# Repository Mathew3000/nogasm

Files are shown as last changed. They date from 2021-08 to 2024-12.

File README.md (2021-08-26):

# Warning
The pcb is not fully tested yet. Might not work as expected.

# Mods
24 LEDs on pc edge <br/>
ESP32 instead of a teensy/teensyduino<br/>
Includes KiCad files<br/>

### Case
The case can be 3D printed without support material. Print at least the top half of the case in white to see the LED display beneath. 
Files will be uploaded once tested.

### PCB
All the Gerber files are included to order a set of PCBs. The PCB has mostly surface-mount components, and is doable with either a soldering iron or solder paste.
The components have been chosen so they can be assembled by the JLCpcb Assembly service. The only part that needs to be sourced from elsewhere and handsoldered is the pressure gauge.

### Vibrator
The vibrator is made from a Mabuchi RS-555PH motor, with an eccentric mass pressed onto the shaft. These can be purchased pre-assembled, or built from the motor and some .88" to 1" diameter cylindrical brass stock.
The vibrator case is compatible with attachments designed for the Hitachi Magic Wand. The motor is press-fit or glued into the two halves of the case.

This repository is a fork of the nogasm project by headcrabned https://github.com/nogasm/nogasm 
This work is licensed under a Creative Commons Attribution-NonCommercial 4.0 International Licence, available at http://creativecommons.org/licenses/by-nc/4.0/.

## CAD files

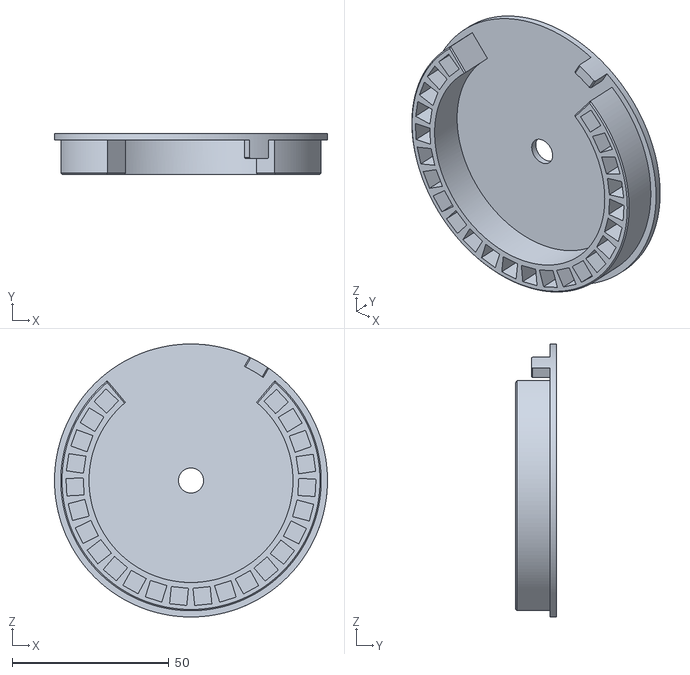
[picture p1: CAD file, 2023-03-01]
case/CaseUpper.stl
87.0 x 13.0 x 87.0

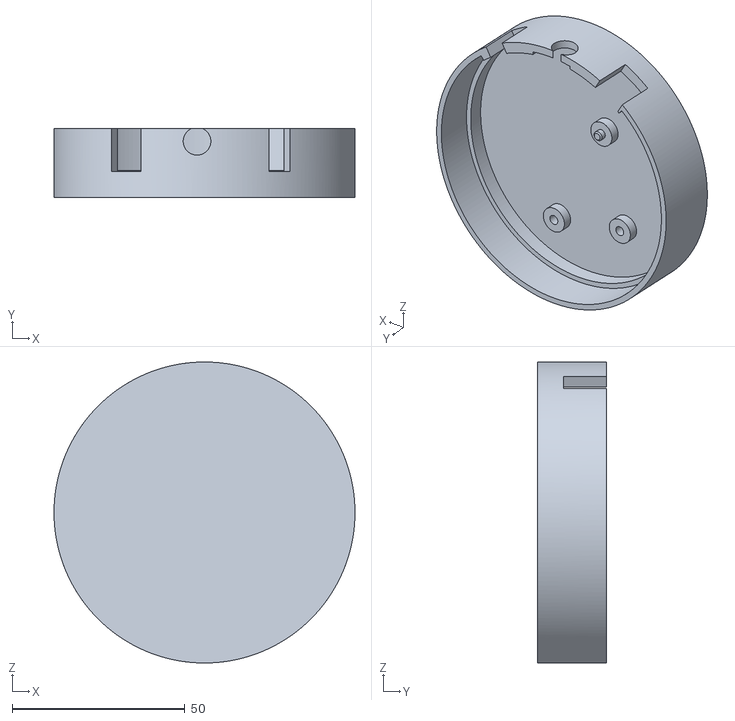
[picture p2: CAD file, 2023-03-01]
case/CaseLower.stl
87.0 x 20.0 x 87.0

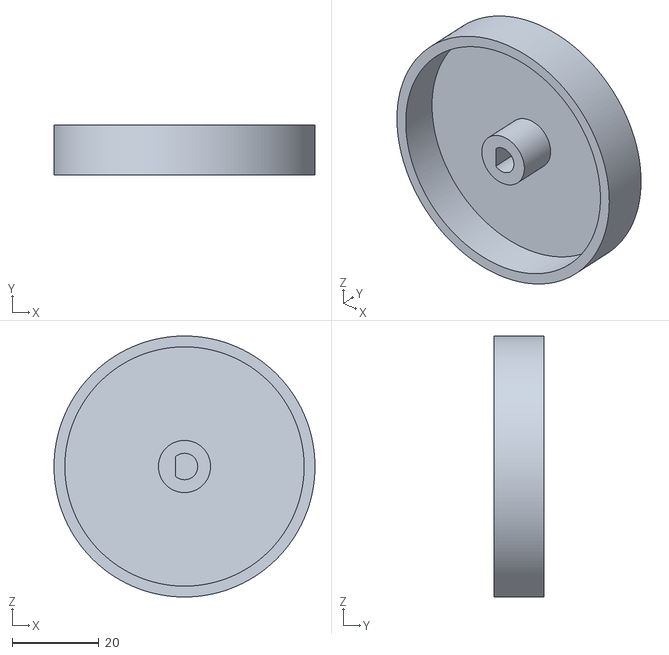
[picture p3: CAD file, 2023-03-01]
case/Knob.stl
60.0 x 11.5 x 60.0

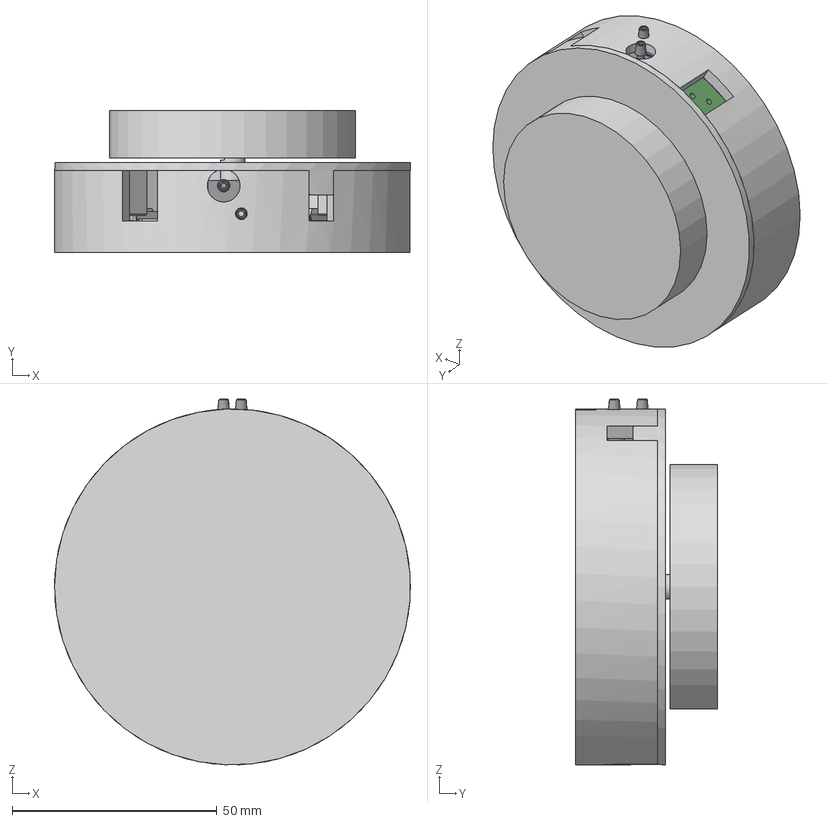
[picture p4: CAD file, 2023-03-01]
case/Case.step
87.0 x 34.6 x 89.4 mm

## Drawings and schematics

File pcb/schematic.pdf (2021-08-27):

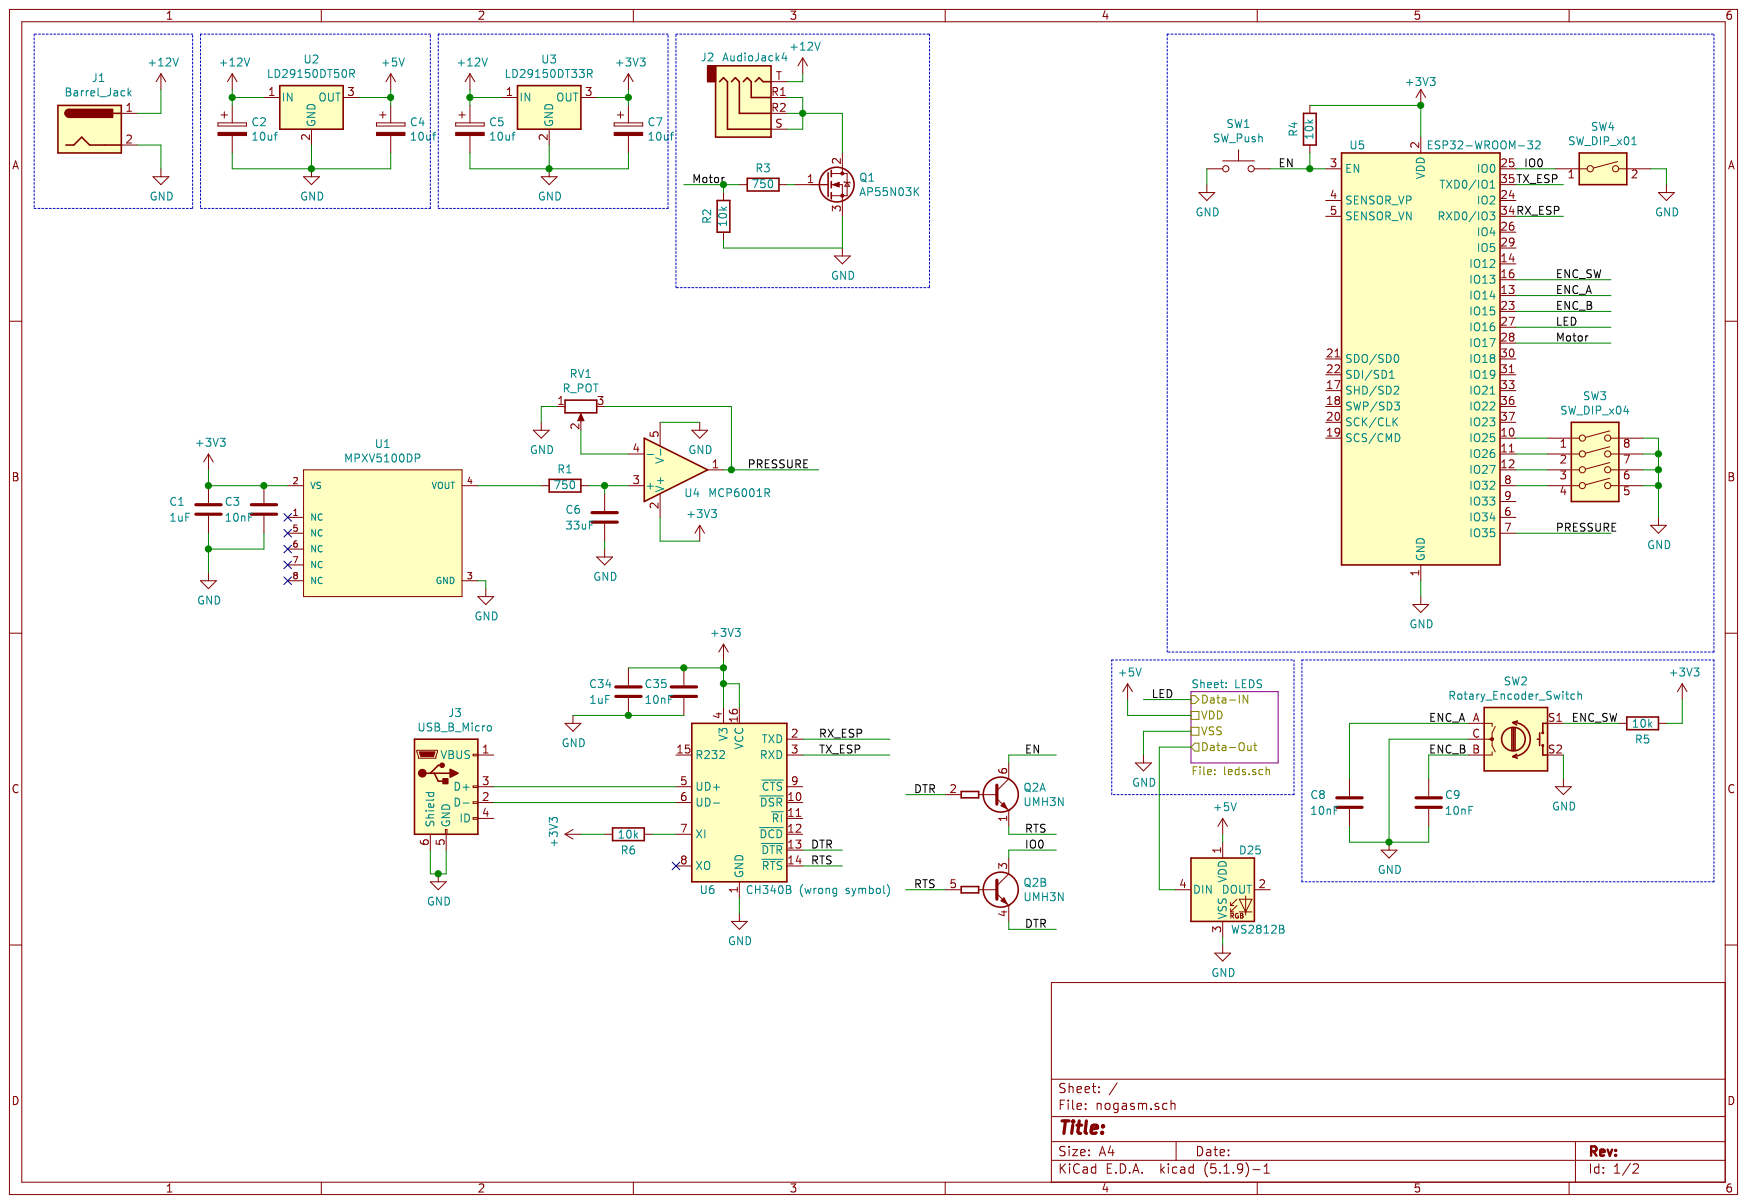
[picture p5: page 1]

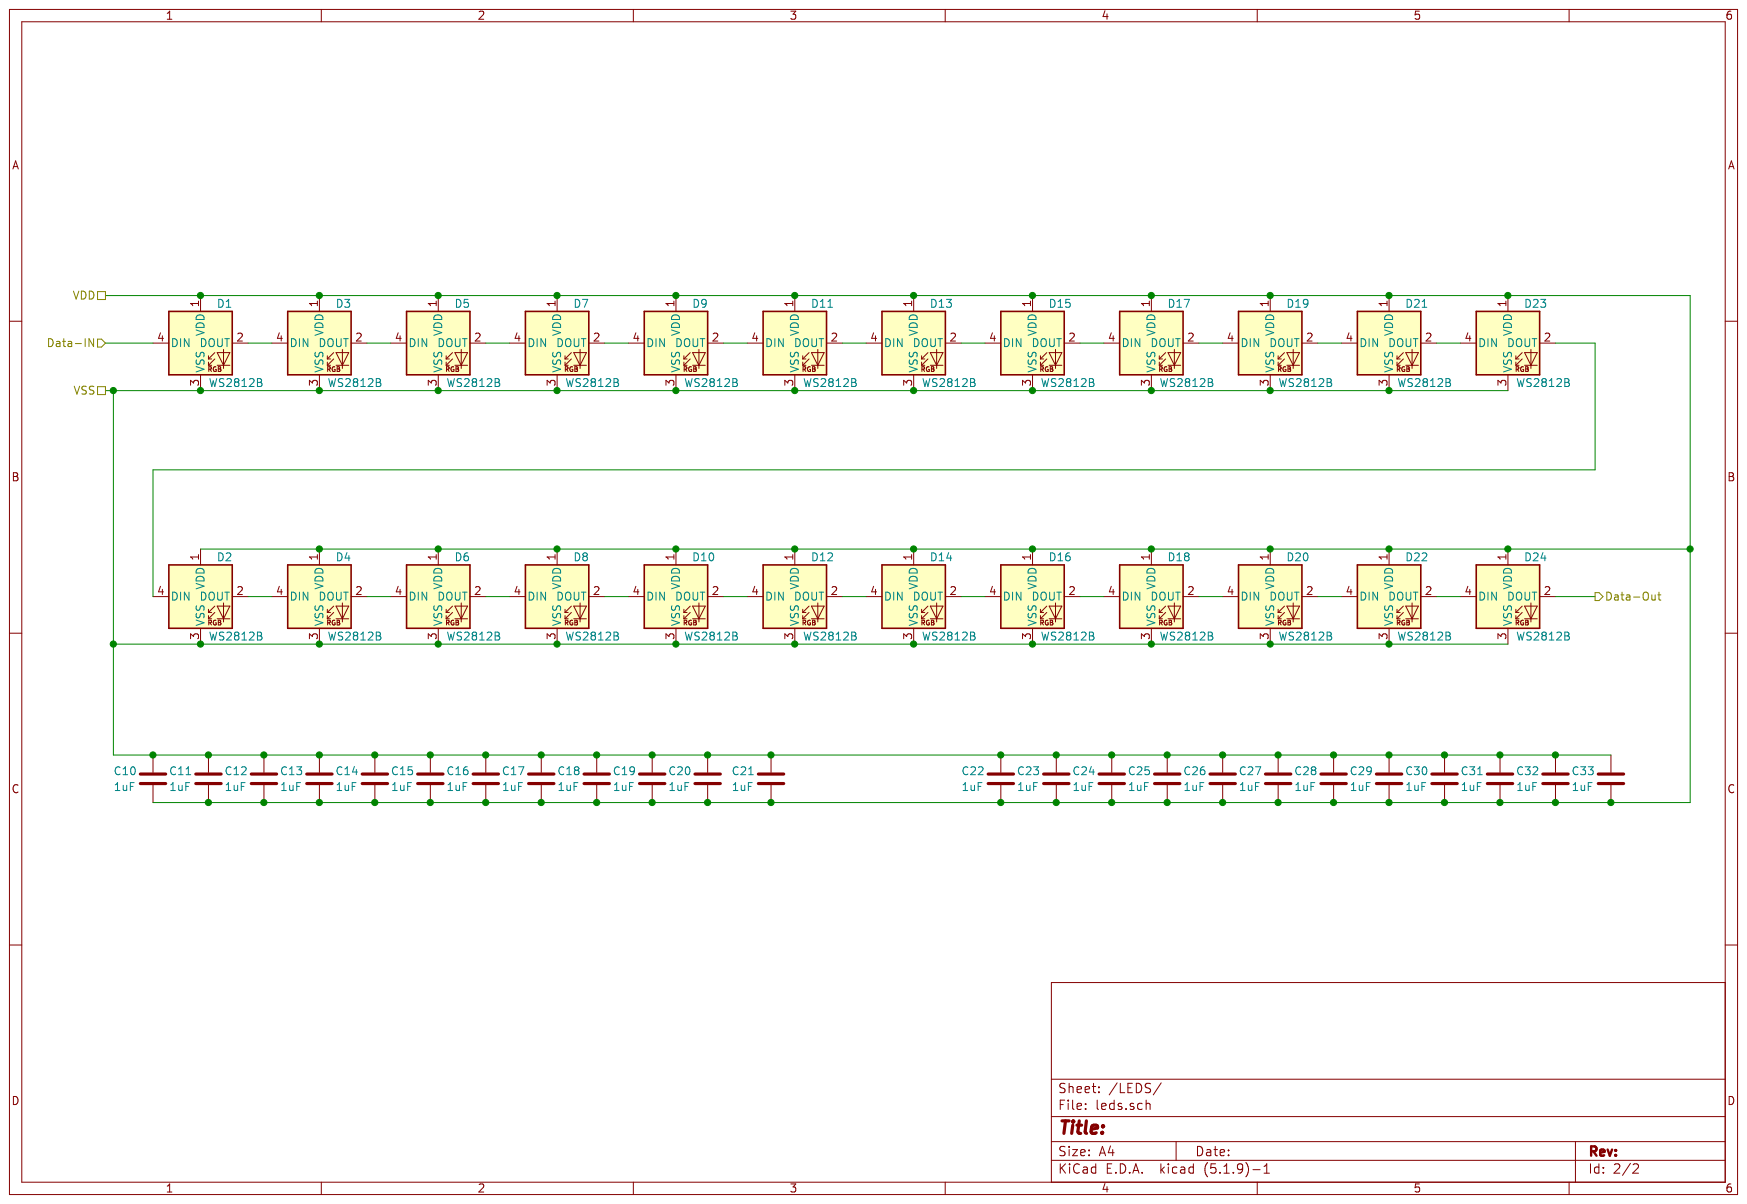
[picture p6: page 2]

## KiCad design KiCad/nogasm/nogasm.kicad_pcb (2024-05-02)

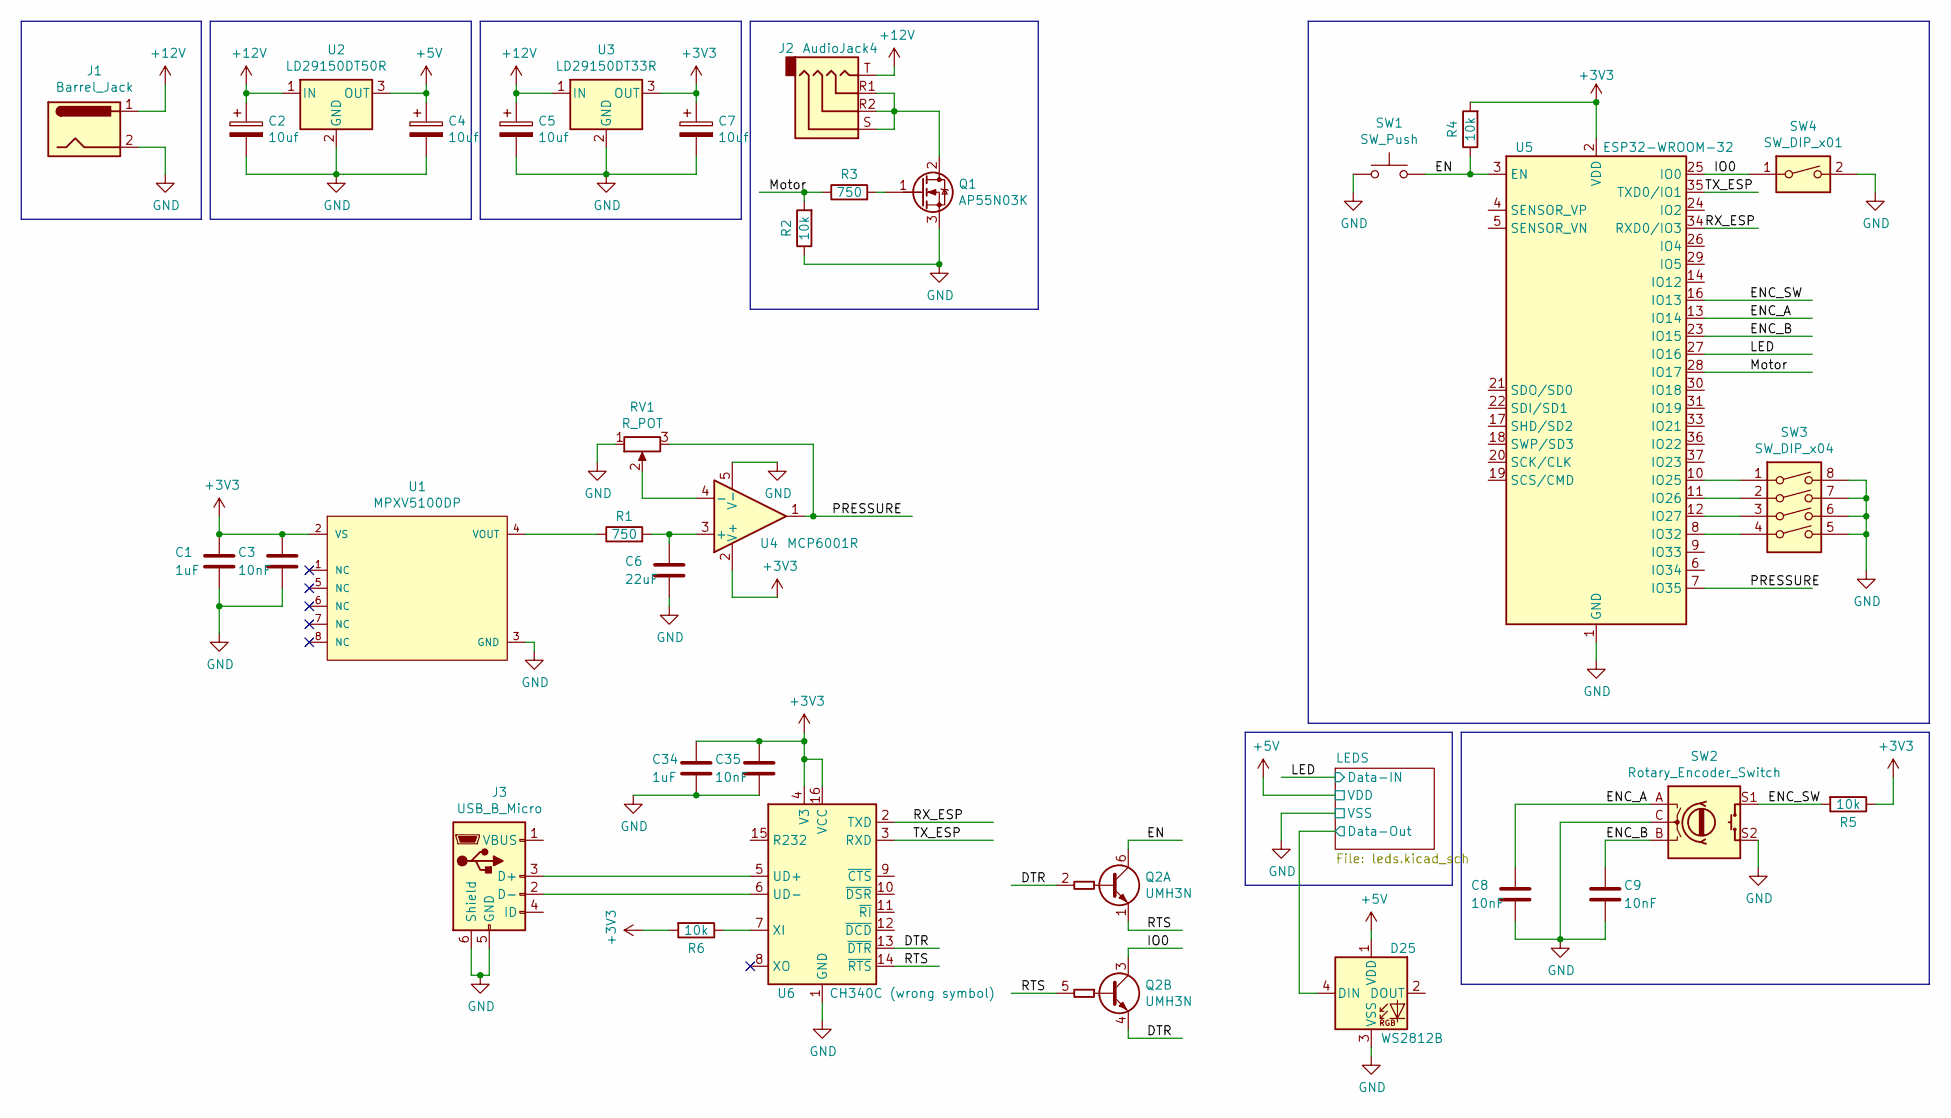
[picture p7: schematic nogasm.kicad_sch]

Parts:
C1, C34: 1uF; C_0603_1608Metric; LCSC C513775
C2, C4, C5, C7: 10uf; CP_Elec_4x4.5; LCSC C249787
C3, C8, C9, C35: 10nF; C_0603_1608Metric; LCSC C100042
C6: 22uF; C_1206_3216Metric; LCSC C159759
D25: WS2812B; LED_WS2812B_PLCC4_5.0x5.0mm_P3.2mm; LCSC C114586
J1: Barrel_Jack; BarrelJack_CUI_PJ-102AH_Horizontal; LCSC C718033
J2: AudioJack4; Jack_3.5mm_PJ320D_Horizontal; LCSC C521460
J3: USB_B_Micro; USB_Micro-B_Wuerth_614105150721_Vertical; LCSC C145795
Q1: AP55N03K; TO-252-2; LCSC C353074
Q2: UMH3N; SOT-363_SC-70-6; LCSC C62892
R1, R3: 750; R_0603_1608Metric; LCSC C724881
R2, R4, R5, R6: 10k; R_0603_1608Metric; LCSC C98220
RV1: R_POT; Potentiometer_Bourns_3314G_Vertical; LCSC C780220
SW1: SW_Push; SW_Push_1P1T_NO_CK_KMR2; LCSC C72443
SW2: Rotary_Encoder_Switch; RotaryEncoder_Alps_EC11E-Switch_Vertical_H20mm; LCSC C470754
SW3: SW_DIP_x04; SW_DIP_SPSTx04_Slide_6.7x11.72mm_W6.73mm_P2.54mm_LowProfile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; LCSC C54950
SW4: SW_DIP_x01; SW_DIP_SPSTx01_Slide_6.7x4.1mm_W6.73mm_P2.54mm_LowProfile_J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; LCSC C54948
U1: MPXV5100DP; Freescale_Semiconductor-SOT1693-1-03_2016-B-MFG; mouser part number 841-MPXV5100DP; digikey description PRESSURE SENSOR GAUGE DUAL 8-SOP
U2: LD29150DT50R; TO-252-2; LCSC C157411
U3: LD29150DT33R; TO-252-2; LCSC C155674
U4: MCP6001R; SOT-23-5; LCSC C154973
U5: ESP32-WROOM-32; LCSC C82899
U6: CH340C (wrong symbol); SOIC-16_3.9x9.9mm_P1.27mm; LCSC C7464026

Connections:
+3V3: C1.1, C3.1, C7.1, C34.1, C35.1, R4.2, R5.1, R6.2, U1.2 (VS), U3.3 (OUT), U4.2 (V+), U5.2 (VDD), U6.4 (V3), U6.16 (VCC)
+5V: C4.1, D25.1 (VDD), U2.3 (OUT); also elsewhere on the board
+12V: C2.1, C5.1, J1.1, J2.T, U2.1 (IN), U3.1 (IN)
/DTR: Q2.2 (B1), Q2.4 (E2), U6.13 (~DTR)
/EN: Q2.6 (C1), R4.1, SW1.2, U5.3 (EN)
/ENC_A: C8.1, SW2.A, U5.13 (IO14)
/ENC_B: C9.1, SW2.B, U5.23 (IO15)
/ENC_SW: R5.2, SW2.S1, U5.16 (IO13)
/IO0: Q2.3 (C2), SW4.1, U5.25 (IO0)
/LED: U5.27 (IO16); also elsewhere on the board
/LEDS/Data-Out: D25.4 (DIN); also elsewhere on the board
/Motor: R2.2, R3.1, U5.28 (IO17)
/PRESSURE: RV1.3, U4.1, U5.7 (IO35)
/RTS: Q2.1 (E1), Q2.5 (B2), U6.14 (~RTS)
/RX_ESP: U5.34 (RXD0/IO3), U6.2 (TXD)
/TX_ESP: U5.35 (TXD0/IO1), U6.3 (RXD)
GND: C1.2, C2.2, C3.2, C4.2, C5.2, C6.2, C7.2, C8.2, C9.2, C34.2, C35.2, D25.3 (VSS), J1.2, J3.5 (GND), J3.6 (Shield), Q1.3 (S), R2.1, RV1.1, SW1.1, SW2.C, SW2.S2, SW3.5, SW3.6, SW3.7, SW3.8, SW4.2, U1.3 (GND), U2.2 (GND), U3.2 (GND), U4.5 (V-), U5.1 (GND), U5.15 (GND), U5.38 (GND), U5.39 (GND), U6.1 (GND); also elsewhere on the board
unnamed: J3.3 (D+), U6.5 (UD+)
unnamed: J3.2 (D-), U6.6 (UD-)
unnamed: J2.R1, J2.R2, J2.S, Q1.2 (D)
unnamed: Q1.1 (G), R3.2
unnamed: R1.1, U1.4 (VOUT)
unnamed: C6.1, R1.2, U4.3 (+)
unnamed: RV1.2, U4.4 (-)
unnamed: SW3.1, U5.10 (IO25)
unnamed: SW3.2, U5.11 (IO26)
unnamed: SW3.3, U5.12 (IO27)
unnamed: SW3.4, U5.8 (IO32)
unnamed: R6.1, U6.7 (XI)

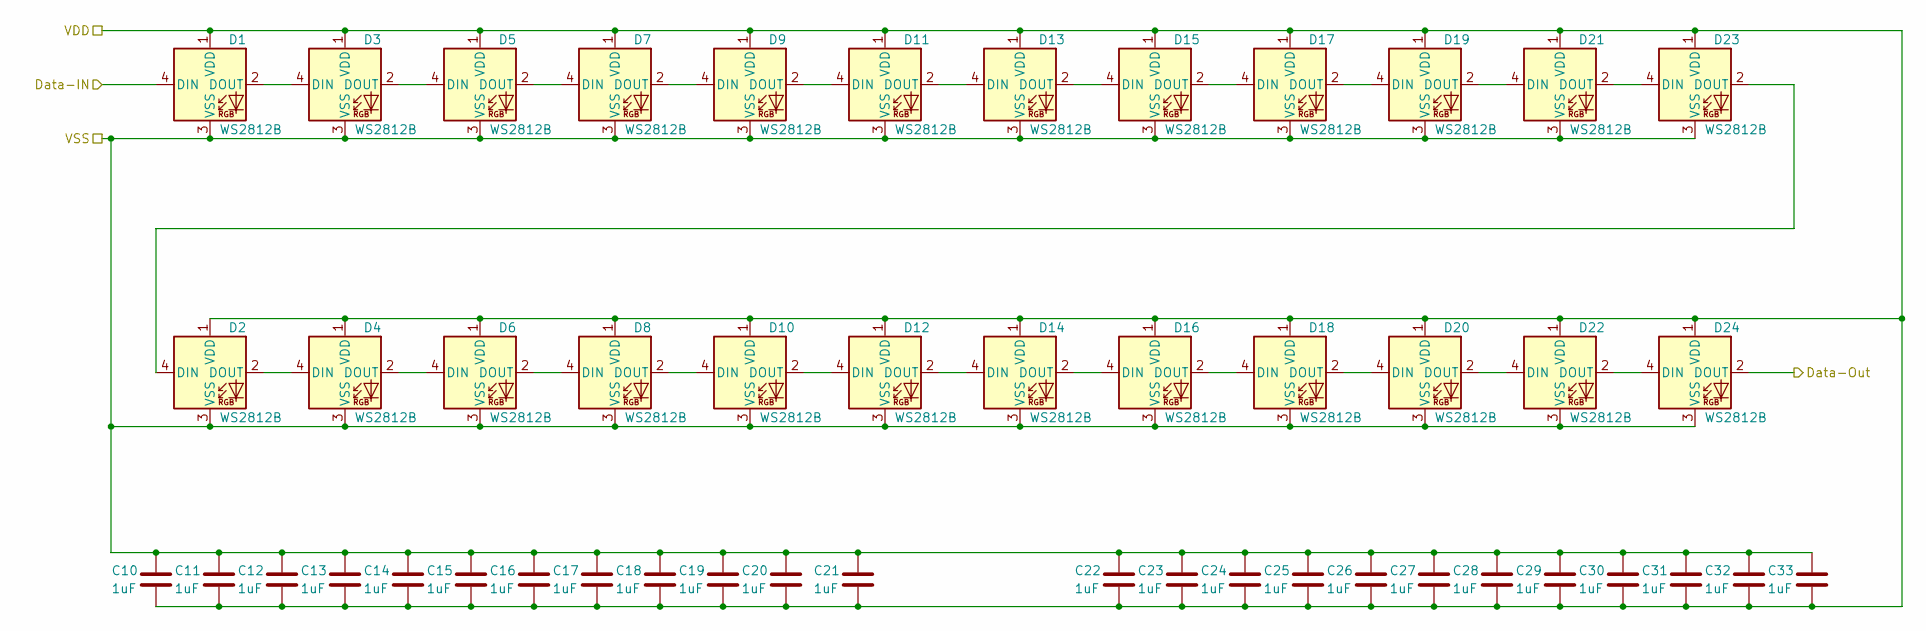
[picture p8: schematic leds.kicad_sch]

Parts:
C10, C11, C12, C13, C14, C15, C16, C17, C18, C19, C20, C21, C22, C23, C24, C25, C26, C27, C28, C29, C30, C31, C32, C33: 1uF; C_0603_1608Metric; LCSC C513775
D1, D2, D3, D4, D5, D6, D7, D8, D9, D10, D11, D12, D13, D14, D15, D16, D17, D18, D19, D20, D21, D22, D23, D24: WS2812B; LED_WS2812B_PLCC4_5.0x5.0mm_P3.2mm; LCSC C114586

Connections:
+5V: C10.2, C11.2, C12.2, C13.2, C14.2, C15.2, C16.2, C17.2, C18.2, C19.2, C20.2, C21.2, C22.2, C23.2, C24.2, C25.2, C26.2, C27.2, C28.2, C29.2, C30.2, C31.2, C32.2, C33.2, D1.1 (VDD), D2.1 (VDD), D3.1 (VDD), D4.1 (VDD), D5.1 (VDD), D6.1 (VDD), D7.1 (VDD), D8.1 (VDD), D9.1 (VDD), D10.1 (VDD), D11.1 (VDD), D12.1 (VDD), D13.1 (VDD), D14.1 (VDD), D15.1 (VDD), D16.1 (VDD), D17.1 (VDD), D18.1 (VDD), D19.1 (VDD), D20.1 (VDD), D21.1 (VDD), D22.1 (VDD), D23.1 (VDD), D24.1 (VDD); also elsewhere on the board
/LED: D1.4 (DIN); also elsewhere on the board
/LEDS/Data-Out: D24.2 (DOUT); also elsewhere on the board
GND: C10.1, C11.1, C12.1, C13.1, C14.1, C15.1, C16.1, C17.1, C18.1, C19.1, C20.1, C21.1, C22.1, C23.1, C24.1, C25.1, C26.1, C27.1, C28.1, C29.1, C30.1, C31.1, C32.1, C33.1, D1.3 (VSS), D2.3 (VSS), D3.3 (VSS), D4.3 (VSS), D5.3 (VSS), D6.3 (VSS), D7.3 (VSS), D8.3 (VSS), D9.3 (VSS), D10.3 (VSS), D11.3 (VSS), D12.3 (VSS), D13.3 (VSS), D14.3 (VSS), D15.3 (VSS), D16.3 (VSS), D17.3 (VSS), D18.3 (VSS), D19.3 (VSS), D20.3 (VSS), D21.3 (VSS), D22.3 (VSS), D23.3 (VSS), D24.3 (VSS); also elsewhere on the board
unnamed: D1.2 (DOUT), D3.4 (DIN)
unnamed: D2.4 (DIN), D23.2 (DOUT)
unnamed: D2.2 (DOUT), D4.4 (DIN)
unnamed: D3.2 (DOUT), D5.4 (DIN)
unnamed: D4.2 (DOUT), D6.4 (DIN)
unnamed: D5.2 (DOUT), D7.4 (DIN)
unnamed: D6.2 (DOUT), D8.4 (DIN)
unnamed: D7.2 (DOUT), D9.4 (DIN)
unnamed: D8.2 (DOUT), D10.4 (DIN)
unnamed: D10.2 (DOUT), D12.4 (DIN)
unnamed: D9.2 (DOUT), D11.4 (DIN)
unnamed: D11.2 (DOUT), D13.4 (DIN)
unnamed: D12.2 (DOUT), D14.4 (DIN)
unnamed: D13.2 (DOUT), D15.4 (DIN)
unnamed: D14.2 (DOUT), D16.4 (DIN)
unnamed: D15.2 (DOUT), D17.4 (DIN)
unnamed: D16.2 (DOUT), D18.4 (DIN)
unnamed: D17.2 (DOUT), D19.4 (DIN)
unnamed: D18.2 (DOUT), D20.4 (DIN)
unnamed: D19.2 (DOUT), D21.4 (DIN)
unnamed: D20.2 (DOUT), D22.4 (DIN)
unnamed: D21.2 (DOUT), D23.4 (DIN)
unnamed: D22.2 (DOUT), D24.4 (DIN)

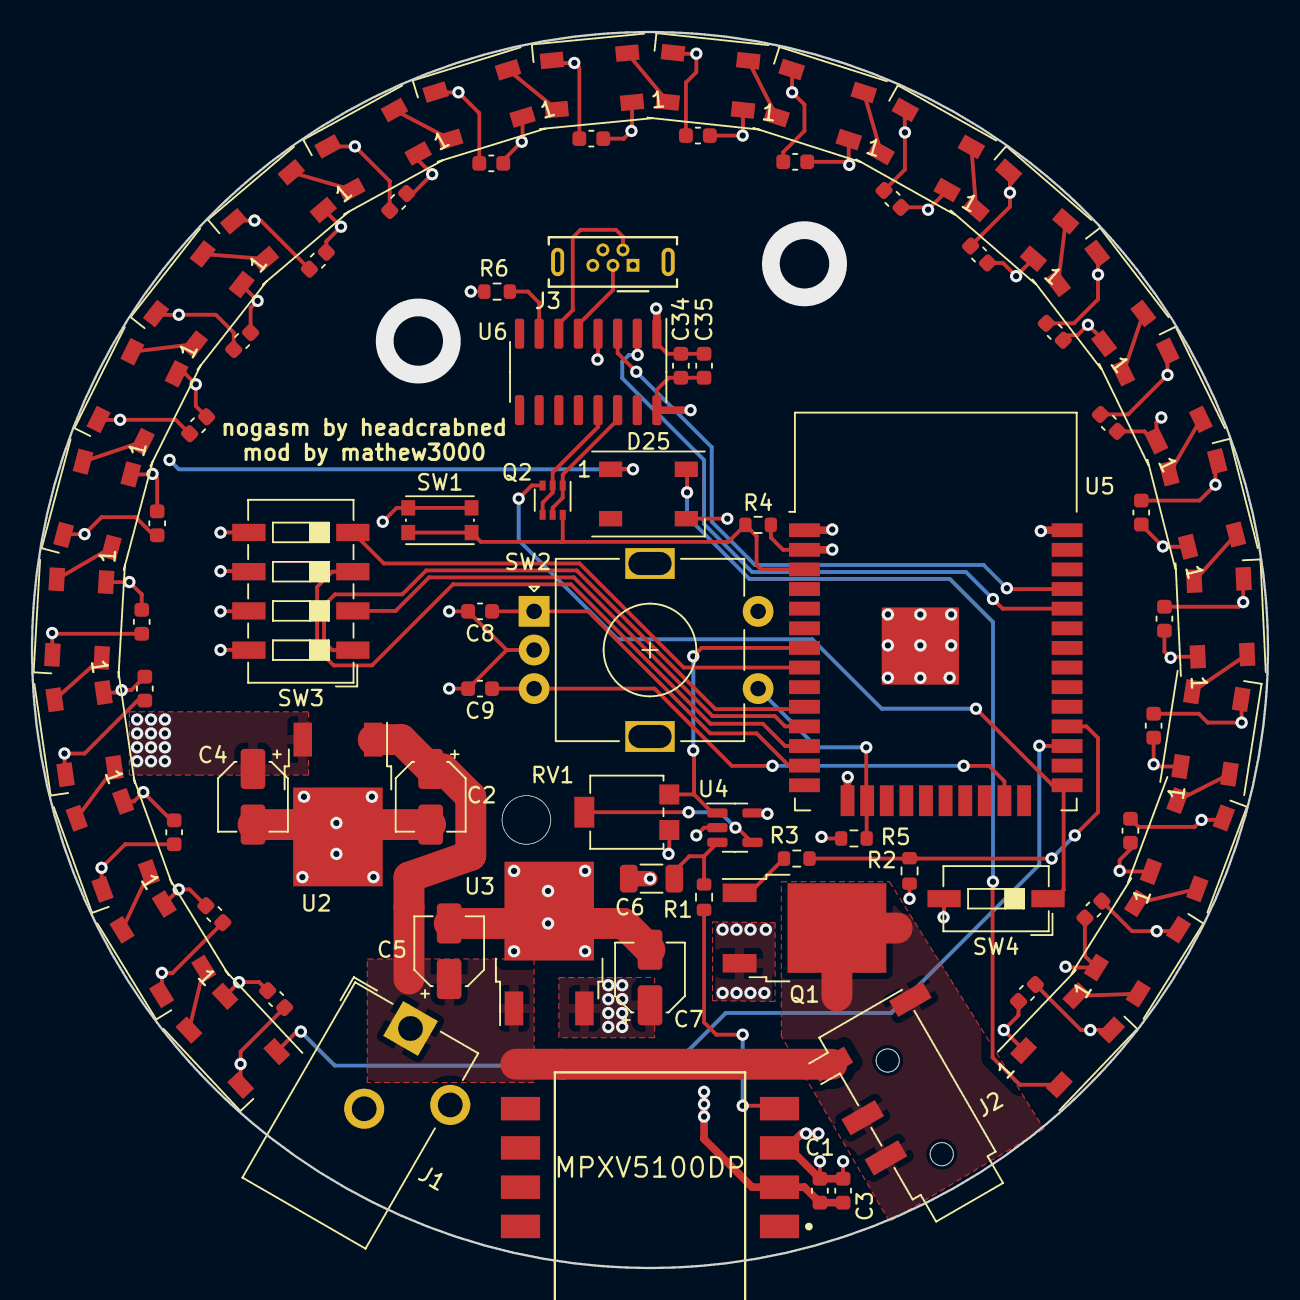
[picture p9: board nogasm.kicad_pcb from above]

Board: 4 copper layers, 80.0 x 80.0 mm, 82 parts (0 on the bottom side), 52 nets.

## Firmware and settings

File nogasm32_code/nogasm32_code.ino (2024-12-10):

// Mathew3000 2021
/*  Ported the nogasm basecode Rev.3 to ESP32
*   Added OTA Upload functionality
*/

// Jul 2016 - Nogasm Code Rev. 3
/* Drives a vibrator and uses changes in pressure of an inflatable buttplug
 * to estimate a user's closeness to orgasm, and turn off the vibrator
 * before that point.
 * A state machine updating at 60Hz creates different modes and option menus
 * that can be identified by the color of the LEDs, especially the RGB LED
 * in the central button/encoder knob.
 * 
 * [Red]    Manual Vibrator Control
 * [Blue]   Automatic vibrator edging, knob adjusts orgasm detection sensitivity
 * [Green]  Setting menu for maximum vibrator speed in automatic mode
 * [White]  Debubbing menu to show data from the pressure sensor ADC
 * [Off]    While still plugged in, holding the button down for >3 seconds turns
 *          the whole device off, until the button is pressed again.
 * 
 * Settings like edging sensitivity, or maximum motor speed are stored in EEPROM,
 * so they are saved through power-cycling.
 * 
 * In the automatic edging mode, the vibrator speed will linearly ramp up to full
 * speed (set in the green menu) over 30 seconds. If a near-orgasm is detected,
 * the vibrator abruptly turns off for 15 seconds, then begins ramping up again.
 * 
 * The motor will beep during power on/off, and if the plug pressure rises above
 * the maximum the board can read - this condition could lead to a missed orgasm 
 * if unchecked. The analog gain for the sensor is adjustable via a trimpot to
 * accomidate different types of plugs that have higher/lower resting pressures.
 * 
 * Motor speed, current pressure, and average pressure are reported via USB serial
 * at 115200 baud. Timestamps can also be enabled, from the main loop.
 * 
 * There is some framework for more features like an adjustable "cool off" time 
 * other than the default 15 seconds, and options for LED brightness and enabling/
 * disabling beeps. Four DIP switches are included on the board to allow users to
 * change other software settings without reflashing code. One example use would 
 * be switch 1 toggling between the defaul ramping motor behavior, and a strict
 * ON/OFF output to the motor that could instead be used to toggle a relay for 
 * driving other toys.
 * 
 * Note - Do not set all 13 LEDs to white at full brightness at once 
 * (RGB 255,255,255) It may overheat the voltage regulator and cause the board 
 * to reset.
 */
//=======Libraries===============================
#include <ESP32Encoder.h>
#include <EEPROM.h>
#include <FastLED.h>
#include <RunningAverage.h>
#include <WiFi.h>
#include <ESPmDNS.h>
#include <WifiUdp.h>
#include <ArduinoOTA.h>

//=======Hardware Setup===============================
//LEDs
#define NUM_LEDS 24
#define LED_PIN 16 
#define LED_TYPE    WS2812B
#define COLOR_ORDER GRB
#define BRIGHTNESS 255

//Encoder
#define ENC_SW   13 //Pushbutton on the encoder
ESP32Encoder myEnc;

//DIP Switches
#define SW1PIN 25 //Dip switch pins, for setting software options without reflashing code
#define SW2PIN 26
#define SW3PIN 27
#define SW4PIN 32

//Motor
#define MOTPIN 17
#define MOT_CHAN 0

//Pressure Sensor Analog In
#define BUTTPIN 35

//=======Software/Timing options=====================
// OTA Settings
const char* ssid = "esp-update-net";
const char* password = "supersavepw";
const char* hostname = "nogasm32";
bool otaActive = false;
int dot = 0;

// Timing settings
#define FREQUENCY 60 //Update frequency in Hz
#define LONG_PRESS_MS 600 //ms requirements for a long press, to move to option menus
#define V_LONG_PRESS_MS 2500 //ms for a very long press, which turns the device off

//Update/render period
#define period (1000/FREQUENCY)
#define longBtnCount (LONG_PRESS_MS / period)

//Running pressure average array length and update frequency
#define RA_HIST_SECONDS 25
#define RA_FREQUENCY 6
#define RA_TICK_PERIOD (FREQUENCY / RA_FREQUENCY)
RunningAverage raPressure(RA_FREQUENCY*RA_HIST_SECONDS);
int sensitivity = 0; //orgasm detection sensitivity, persists through different states

//=======State Machine Modes=========================
#define MANUAL      1
#define AUTO        2
#define OPT_SPEED   3
#define OPT_RAMPSPD 4
#define OPT_BEEP    5
#define OPT_PRES    6


//Button states - no press, short press, long press
#define BTN_NONE   0
#define BTN_SHORT  1
#define BTN_LONG   2
#define BTN_V_LONG 3


uint8_t state = MANUAL;
//=======Global Settings=============================
//DIP switch options:
uint8_t MOT_MAX =   179; //By default, motor speed only ever reaches 179. Alternative is 255
bool SW2 =        false;
bool SW3 =        false;
bool SW4 =        false;
#define MOT_MIN 20  // Motor PWM minimum.  It needs a little more than this to start.

CRGB leds[NUM_LEDS];

int pressure = 0;
int avgPressure = 0; //Running 25 second average pressure
//int bri =100; //Brightness setting
int rampTimeS = 30; //Ramp-up time, in seconds
#define DEFAULT_PLIMIT 600
int pLimit = DEFAULT_PLIMIT; //Limit in change of pressure before the vibrator turns off
int maxSpeed = 255; //maximum speed the motor will ramp up to in automatic mode
float motSpeed = 0; //Motor speed, 0-255 (float to maintain smooth ramping to low speeds)

//=======EEPROM Addresses============================
//128b available on teensy LC
#define BEEP_ADDR         1
#define MAX_SPEED_ADDR    2
#define SENSITIVITY_ADDR  3
//#define RAMPSPEED_ADDR    4 //For now, ramp speed adjustments aren't implemented

//=======Setup=======================================
//Beep out tones over the motor by frequency (1047,1396,2093) may work well
void beep_motor(int f1, int f2, int f3){
  /*
  if(motSpeed > 245) analogWrite(MOTPIN, 245); //make sure the frequency is audible
  else if(motSpeed < 10) analogWrite(MOTPIN, 10);
  analogWriteFrequency(MOTPIN, f1);
  delay(250);
  analogWriteFrequency(MOTPIN, f2);
  delay(250);
  analogWriteFrequency(MOTPIN, f3);
  delay(250);
  analogWriteFrequency(MOTPIN, 440);
  analogWrite(MOTPIN,motSpeed);*/
}

void setup() {
  FastLED.addLeds<LED_TYPE, LED_PIN, COLOR_ORDER>(leds, NUM_LEDS).setCorrection(TypicalLEDStrip);
  // limit power draw to .6A at 5v... Didn't seem to work in my FastLED version though
  //FastLED.setMaxPowerInVoltsAndMilliamps(5,DEFAULT_PLIMIT);
  FastLED.setBrightness(BRIGHTNESS);
  // OTA Setup
  // Wait for boot
  for(int dot = 0; dot < NUM_LEDS; dot++)
  {
    leds[dot] = CRGB::Gold;
    FastLED.show();
    delay(100);
    leds[dot] = CRGB::Black;
  }
  for(int dot = NUM_LEDS-1; dot >= 0; dot--)
  {
    leds[dot] = CRGB::Gold;
    FastLED.show();
    delay(100);
    leds[dot] = CRGB::Black;
  }
  WiFi.mode(WIFI_STA);
  WiFi.begin(ssid, password);
  otaActive = (WiFi.waitForConnectResult() == WL_CONNECTED);
  // Setup OTA only if WiFi connected
  if(otaActive)
  {
    ArduinoOTA
    .onStart([]() {
      String type;
      if (ArduinoOTA.getCommand() == U_FLASH)
        type = "sketch";
      else // U_SPIFFS
        type = "filesystem";
    });
    ArduinoOTA.setHostname(hostname);
    ArduinoOTA.begin();
    for(int i = 0; i < (NUM_LEDS>>1); i++)
    {
      leds[i<<1] = CRGB::DarkGreen;
    }
    FastLED.show();
  }

  pinMode(ENC_SW,   INPUT); //Pin to read quadrature pulses from encoder

  myEnc.attachHalfQuad(15, 14); //encoder inputs on pins 14,15

  pinMode(SW1PIN,   INPUT_PULLUP); //Set DIP switch pins as inputs
  pinMode(SW2PIN,   INPUT_PULLUP);
  pinMode(SW3PIN,   INPUT_PULLUP);
  pinMode(SW4PIN,   INPUT_PULLUP);

  pinMode(MOTPIN,OUTPUT); //Enable "analog" out (PWM)
  
  pinMode(BUTTPIN,INPUT); //default is 10 bit resolution (1024), 0-3.3
  
  raPressure.clear(); //Initialize a running pressure average

  digitalWrite(MOTPIN, LOW);//Make sure the motor is off
  ledcSetup(MOT_CHAN, 500, 8);
  ledcAttachPin(MOTPIN, MOT_CHAN);

  delay(3000); // 3 second delay for recovery

  //If a pin reads low, the switch is enabled. Here, we read in the DIP settings
  //Right now, only SW1 is used, for enabling higher maximum motor speed.
  if(digitalRead(SW1PIN)){
    MOT_MAX = 179; //At the default low position, limit the motor speed
  }
  else{
    MOT_MAX = 255; //When SW1 is flipped high, allow higher motor speeds
  }
  SW2 = (digitalRead(SW2PIN) == LOW);
  SW3 = (digitalRead(SW3PIN) == LOW);
  SW4 = (digitalRead(SW4PIN) == LOW);

  Serial.begin(115200);

  //Recall saved settings from memory
  sensitivity = EEPROM.read(SENSITIVITY_ADDR);
  maxSpeed = min(EEPROM.read(MAX_SPEED_ADDR),MOT_MAX); //Obey the MOT_MAX the first power  cycle after chaning it.
  beep_motor(1047,1396,2093); //Power on beep
}

//=======LED Drawing Functions=================

void showKnobRGB(const CRGB& rgb)
{
  //this led does not exist
  //analogWrite(REDPIN,   rgb.r );
  //analogWrite(GREENPIN, rgb.g );
  //analogWrite(BLUEPIN,  rgb.b );
}

//Draw a "cursor", one pixel representing either a pressure or encoder position value
//C1,C2,C3 are colors for each of 3 revolutions over the 13 LEDs (39 values)
void draw_cursor_3(int pos,CRGB C1, CRGB C2, CRGB C3){
  pos = constrain(pos,0,NUM_LEDS*3-1);
  int colorNum = pos/NUM_LEDS; //revolution number
  int cursorPos = pos % NUM_LEDS; //place on circle, from 0-12
  switch(colorNum){
    case 0:
      leds[cursorPos] = C1;
      break;
    case 1:
      leds[cursorPos] = C2;
      break;
    case 2:
      leds[cursorPos] = C3;
      break;
  }
}

//Draw a "cursor", one pixel representing either a pressure or encoder position value
void draw_cursor(int pos,CRGB C1){
  pos = constrain(pos,0,NUM_LEDS-1);
  leds[pos] = C1;
}

//Draw 3 revolutions of bars around the LEDs. From 0-39, 3 colors
void draw_bars_3(int pos,CRGB C1, CRGB C2, CRGB C3){
  pos = constrain(pos,0,NUM_LEDS*3-1);
  int colorNum = pos/NUM_LEDS; //revolution number
  int barPos = pos % NUM_LEDS; //place on circle, from 0-12
  switch(colorNum){
    case 0:
      fill_gradient_RGB(leds,0,C1,barPos,C1);
      //leds[barPos] = C1;
      break;
    case 1:
      fill_gradient_RGB(leds,0,C1,barPos,C2);
      break;
    case 2:
      fill_gradient_RGB(leds,0,C2,barPos,C3);
      break;
  }
}

//Provide a limited encoder reading corresponting to tacticle clicks on the knob.
//Each click passes through 4 encoder pulses. This reduces it to 1 pulse per click
int encLimitRead(int minVal, int maxVal){
  if(myEnc.getCount()>maxVal*4)myEnc.setCount(maxVal*4);
  else if(myEnc.getCount()<minVal*4) myEnc.setCount(minVal*4);
  return constrain(myEnc.getCount()/4,minVal,maxVal);
}

//=======Program Modes/States==================

// Manual vibrator control mode (red), still shows orgasm closeness in background
void run_manual() {
  //In manual mode, only allow for 13 cursor positions, for adjusting motor speed.
  int knob = encLimitRead(0,NUM_LEDS - 1);
  motSpeed = map(knob, 0, NUM_LEDS - 1, 0., (float)MOT_MAX);
  ledcWrite(MOT_CHAN, motSpeed);

  //gyrGraphDraw(avgPressure, 0, 4 * 3 * NUM_LEDS);
  int presDraw = map(constrain(pressure - avgPressure, 0, pLimit),0,pLimit,0,NUM_LEDS*3);
  draw_bars_3(presDraw, CRGB::Green,CRGB::Yellow,CRGB::Red);
  draw_cursor(knob, CRGB::Red);
}

// Automatic edging mode, knob adjust sensitivity.
void run_auto() {
  static float motIncrement = 0.0;
  motIncrement = ((float)maxSpeed / ((float)FREQUENCY * (float)rampTimeS));

  int knob = encLimitRead(0,(3*NUM_LEDS)-1);
  sensitivity = knob*4; //Save the setting if we leave and return to this state
  //Reverse "Knob" to map it onto a pressure limit, so that it effectively adjusts sensitivity
  pLimit = map(knob, 0, 3 * (NUM_LEDS - 1), 600, 1); //set the limit of delta pressure before the vibrator turns off
  //When someone clenches harder than the pressure limit
  if (pressure - avgPressure > pLimit) {
    motSpeed = -.5*(float)rampTimeS*((float)FREQUENCY*motIncrement);//Stay off for a while (half the ramp up time)
  }
  else if (motSpeed < (float)maxSpeed) {
    motSpeed += motIncrement;
  }
  if (motSpeed > MOT_MIN) {
    ledcWrite(MOT_CHAN, (int) motSpeed);
  } else {
    ledcWrite(MOT_CHAN, 0);
  }

  int presDraw = map(constrain(pressure - avgPressure, 0, pLimit),0,pLimit,0,NUM_LEDS*3);
  draw_bars_3(presDraw, CRGB::Green,CRGB::Yellow,CRGB::Red);
  draw_cursor_3(knob, CRGB(50,50,200),CRGB::Blue,CRGB::Purple);

}

//Setting menu for adjusting the maximum vibrator speed automatic mode will ramp up to
void run_opt_speed() {
  Serial.println("speed settings");
  int knob = encLimitRead(0,NUM_LEDS - 1);
  motSpeed = map(knob, 0, NUM_LEDS - 1, 0., (float)MOT_MAX);
  ledcWrite(MOT_CHAN, motSpeed);
  maxSpeed = motSpeed; //Set the maximum ramp-up speed in automatic mode
  //Little animation to show ramping up on the LEDs
  static int visRamp = 0;
  if(visRamp <= FREQUENCY*NUM_LEDS-1) visRamp += 16;
  else visRamp = 0;
  draw_bars_3(map(visRamp,0,(NUM_LEDS-1)*FREQUENCY,0,knob),CRGB::Green,CRGB::Green,CRGB::Green);
}

//Not yet added, but adjusts how quickly the vibrator turns back on after being triggered off
void run_opt_rampspd() {
  Serial.println("rampSpeed");
}

//Also not completed, option for enabling/disabling beeps
void run_opt_beep() {
  Serial.println("Brightness Settings");
}

//Simply display the pressure analog voltage. Useful for debugging sensitivity issues.
void run_opt_pres() {
  int p = map(analogRead(BUTTPIN),0,4095,0,NUM_LEDS-1);
  draw_cursor(p,CRGB::White);
}

//Poll the knob click button, and check for long/very long presses as well
uint8_t check_button(){
  static bool lastBtn = LOW;
  static unsigned long keyDownTime = 0;
  uint8_t btnState = BTN_NONE;
  bool thisBtn = digitalRead(ENC_SW);

  //Detect single presses, no repeating, on keyup
  if(thisBtn == HIGH && lastBtn == LOW){
    keyDownTime = millis();
  }
  
  if (thisBtn == LOW && lastBtn == HIGH) { //there was a keyup
    if((millis()-keyDownTime) >= V_LONG_PRESS_MS){
      btnState = BTN_V_LONG;
    }
    else if((millis()-keyDownTime) >= LONG_PRESS_MS){
      btnState = BTN_LONG;
      }
    else{
      btnState = BTN_SHORT;
      }
    }

  lastBtn = thisBtn;
  return btnState;
}

//run the important/unique parts of each state. Also, set button LED color.
void run_state_machine(uint8_t state){
  switch (state) {
      case MANUAL:
        showKnobRGB(CRGB::Red);
        run_manual();
        break;
      case AUTO:
        showKnobRGB(CRGB::Blue);
        run_auto();
        break;
      case OPT_SPEED:
        showKnobRGB(CRGB::Green);
        run_opt_speed();
        break;
      case OPT_RAMPSPD:
        showKnobRGB(CRGB::Yellow);
        run_opt_rampspd();
        break;
      case OPT_BEEP:
        showKnobRGB(CRGB::Purple);
        run_opt_beep();
        break;
      case OPT_PRES:
        showKnobRGB(CRGB::White);
        run_opt_pres();
        break;
      default:
        run_manual();
        break;
    }
}

//Switch between state machine states, and reset the encoder position as necessary
//Returns the next state to run. Very long presses will turn the system off (sort of)
uint8_t set_state(uint8_t btnState, uint8_t state){
  if(btnState == BTN_NONE){
    return state;
  }
  if(btnState == BTN_V_LONG){
    //Turn the device off until woken up by the button
    Serial.println("power off");
    fill_gradient_RGB(leds,0,CRGB::Black,NUM_LEDS-1,CRGB::Black);//Turn off LEDS
    FastLED.show();
    showKnobRGB(CRGB::Black);
    ledcWrite(MOT_CHAN, 0);
    beep_motor(2093,1396,1047);
    ledcWrite(MOT_CHAN, 0); //Turn Motor off
    while(!digitalRead(ENC_SW))delay(1);
    beep_motor(1047,1396,2093);
    return MANUAL ;
  }
  else if(btnState == BTN_SHORT){
    switch(state){
      case MANUAL:
        myEnc.setCount(sensitivity);//Whenever going into auto mode, keep the last sensitivity
        motSpeed = 0; //Also reset the motor speed to 0
        return AUTO;
      case AUTO:
        myEnc.setCount(0);//Whenever going into manual mode, set the speed to 0.
        motSpeed = 0;
        EEPROM.write(SENSITIVITY_ADDR, sensitivity);
        return MANUAL;
      case OPT_SPEED:
        myEnc.setCount(0);
        EEPROM.write(MAX_SPEED_ADDR, maxSpeed);
        //return OPT_RAMPSPD;
        //return OPT_BEEP;
        motSpeed = 0;
        ledcWrite(MOT_CHAN, motSpeed); //Turn the motor off for the white pressure monitoring mode
        return OPT_PRES; //Skip beep and rampspeed settings for now
      case OPT_RAMPSPD: //Not yet implimented
        //motSpeed = 0;
        //myEnc.write(0);
        return OPT_BEEP;
      case OPT_BEEP:
        myEnc.setCount(0);
        return OPT_PRES;
      case OPT_PRES:
        myEnc.setCount(map(maxSpeed,0,255,0,4*(NUM_LEDS)));//start at saved value
        return OPT_SPEED;
    }
  }
  else if(btnState == BTN_LONG){
    switch (state) {
          case MANUAL:
            myEnc.setCount(map(maxSpeed,0,255,0,4*(NUM_LEDS)));//start at saved value
            return OPT_SPEED;
          case AUTO:
            myEnc.setCount(map(maxSpeed,0,255,0,4*(NUM_LEDS)));//start at saved value
            return OPT_SPEED;
          case OPT_SPEED:
            myEnc.setCount(0);
            return MANUAL;
          case OPT_RAMPSPD:
            return MANUAL;
          case OPT_BEEP:
            return MANUAL;
          case OPT_PRES:
            myEnc.setCount(0);
            return MANUAL;
        }
  }
  else return MANUAL;
}

//=======Main Loop=============================
void loop() {
  if(otaActive)
  {
    ArduinoOTA.handle();
    if(!digitalRead(ENC_SW)) 
    {
      otaActive = false;
      for(int i = 0; i < (NUM_LEDS>>1); i++)
      {
        leds[i<<1] = CRGB::Black;
      }
      FastLED.show();
    }
  }
  else // Nogasm loop
  {
    static uint8_t state = MANUAL;
    static int sampleTick = 0;
    //Run this section at the update frequency (default 60 Hz)
    if (millis() % period == 0) {
      delay(1);
      
      sampleTick++; //Add pressure samples to the running average slower than 60Hz
      if (sampleTick % RA_TICK_PERIOD == 0) {
        raPressure.addValue(pressure);
        avgPressure = raPressure.getAverage();
      }
      
      pressure = analogRead(BUTTPIN);
      fadeToBlackBy(leds,NUM_LEDS,20); //Create a fading light effect. LED buffer is not otherwise cleared
      uint8_t btnState = check_button();
      state = set_state(btnState,state); //Set the next state based on this state and button presses
      run_state_machine(state);
      FastLED.show(); //Update the physical LEDs to match the buffer in software

      //Alert that the Pressure voltage amplifier is railing, and the trim pot needs to be adjusted
      if(pressure > 4030)beep_motor(2093,2093,2093); //Three high beeps

      //Report pressure and motor data over USB for analysis / other uses. timestamps disabled by default
      //Serial.print(millis()); //Timestamp (ms)
      //Serial.print(",");
      Serial.print(motSpeed); //Motor speed (0-255)
      Serial.print(",");
      Serial.print(pressure); //(Original ADC value - 12 bits, 0-4095)
      Serial.print(",");
      Serial.println(avgPressure); //Running average of (default last 25 seconds) pressure
    }
  }
}

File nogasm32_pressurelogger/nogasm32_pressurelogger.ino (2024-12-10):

// OTA Stuff
#include <WiFi.h>
#include <ESPmDNS.h>
#include <WiFiUdp.h>
#include <ArduinoOTA.h>
#include <FastLED.h>
#include <ESPTelnet.h>


#define NUM_LEDS 24
#define DATA_PIN 16
CRGB leds[NUM_LEDS];
int dot = 0;
int dir = 1;

const char* ssid = "esp-update-net";
const char* password = "supersavepw";
const char* hostname = "pressurelogger";
bool otaActive = false;
bool wifiActive = false;

// Telnet
ESPTelnet telnet;
bool telnetActive = false;

//Encoder
#define ENC_SW   13 //Pushbutton on the encoder
//Pressure Sensor Analog In
#define BUTTPIN 35
#define FREQUENCY 120
#define LED_FREQUENCY 10
//Update/render period
#define period (1000/FREQUENCY)
#define ledPeriod (1000/LED_FREQUENCY)

long lastUpdate = 0;
long lastLedCycle = 0;

void setup() {
  // Wait for boot
  FastLED.addLeds<WS2812B, DATA_PIN, GRB>(leds, NUM_LEDS);
  for(int dot = 0; dot < NUM_LEDS; dot++)
  {
    leds[dot] = CRGB::Gold;
    FastLED.show();
    delay(100);
    leds[dot] = CRGB::Black;
  }
  for(int dot = NUM_LEDS-1; dot >= 0; dot--)
  {
    leds[dot] = CRGB::Gold;
    FastLED.show();
    delay(100);
    leds[dot] = CRGB::Black;
  }
  WiFi.mode(WIFI_STA);
  WiFi.setHostname(hostname);
  WiFi.begin(ssid, password);
  wifiActive = (WiFi.waitForConnectResult() == WL_CONNECTED);
  otaActive = wifiActive;
  // Setup OTA only if WiFi connected
  if(otaActive)
  {
    ArduinoOTA
    .onStart([]() {
      String type;
      if (ArduinoOTA.getCommand() == U_FLASH)
        type = "sketch";
      else // U_SPIFFS
        type = "filesystem";
    });
    ArduinoOTA.setHostname(hostname);
    ArduinoOTA.begin();
    for(int i = 0; i < (NUM_LEDS>>1); i++)
    {
      leds[i<<1] = CRGB::DarkGreen;
    }
    FastLED.show();
  }
  if(wifiActive)
  {
    setupTelnet();
  }
  pinMode(ENC_SW,   INPUT); //Pin to read when encoder is pressed
  digitalWrite(ENC_SW, HIGH); // Encoder switch pullup
  pinMode(BUTTPIN,INPUT); //default is 12 bit resolution (4096), 0-3.3

  Serial.begin(115200);

}

//=======Main Loop=============================
void loop() {
  if(wifiActive)
  {
    telnet.loop();
  }
  if(otaActive)
  {
    ArduinoOTA.handle();
    if(!digitalRead(ENC_SW)) 
    {
      otaActive = false;
    }
  }
  else
  {
    if (millis() - period > lastUpdate) {      
      long pressure = analogRead(BUTTPIN);
      //Report pressure and motor data over USB for analysis / other uses.
      Serial.print(millis()); //Timestamp (ms)
      Serial.print(",");
      Serial.print(pressure); //(Original ADC value - 12 bits, 0-4095)
      Serial.print(",");
      Serial.println(digitalRead(ENC_SW));
      // Report same date ofer telnet if available
      if(telnetActive)
      {
        telnet.print(String(millis())); //Timestamp (ms)
        telnet.print(",");
        telnet.print(String(pressure)); //(Original ADC value - 12 bits, 0-4095)
        telnet.print(",");
        telnet.print(String(digitalRead(ENC_SW)));
        telnet.print("\r\n");
      }
      lastUpdate = millis();
    }
    if(millis() - ledPeriod > lastLedCycle) 
    {
      leds[dot] = CRGB::DarkRed;
      FastLED.show();
      leds[dot] = CRGB::Black;
      dot = dot + dir;
      if(dot >= NUM_LEDS - 1) dir = -1;
      if(dot <= 0) dir = 1; 
      lastLedCycle = millis();
    }
  }
}

// Telnet
void setupTelnet() {  
  // passing on functions for various telnet events
  telnet.onConnect(onTelnetConnect);
  telnet.onReconnect(onTelnetReconnect);
  telnet.onDisconnect(onTelnetDisconnect);
  telnet.begin();
}

void onTelnetConnect(String ip) {
  telnetActive = true;
  telnet.print(hostname);
  Serial.print("Telnet!");
}

void onTelnetDisconnect(String ip) {
  telnetActive = false;
}

void onTelnetReconnect(String ip) {
  telnetActive = true;
}

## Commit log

2021-08-08 Added ESP-32 Based PCB project
    [leds.sch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]
2021-08-08 Added text and mounting holes
    [nogasm-B_Cu.gbr, nogasm-B_Mask.gbr, nogasm-B_Paste.gbr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]
2021-08-26 Added ESP32-Based KiCad files
    [nogasm.kicad_pcb, nogasm.sch]
2021-08-26 Moved kicad outputs to pcb folder
    [RoundPCB.GBL, RoundPCB.GBO, RoundPCB.GBS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]
2021-08-26 Corrected partnumber for 3v3 LDO
    [nogasm-B_Cu.gbr, nogasm-B_Mask.gbr, nogasm-B_Paste.gbr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]
2021-08-26 Fixed BOM to include correct 3v3 LDO
    [nogasm_bom_jlc.csv]
2021-08-26 Removed all STL files and incompatible code.
    [CaseLid.STL, CaseLower.STEP, CaseLower.STL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]
2021-08-26 Added code for nogasm32 pressure logger
2021-08-26 Changed Pressurelogger to use non ADC2 pin
2021-08-26 Updated PCB documents to fix ESP ADC channel
    [nogasm-B_Cu.gbr, nogasm-B_Mask.gbr, nogasm-B_Paste.gbr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]
2021-08-26 Updated PCB Files
    [nogasm-B_Cu.gbr, nogasm-B_Mask.gbr, nogasm-B_Paste.gbr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]
2021-08-27 Added Autoflash for ESP32 and Center-LED
    [nogasm.kicad_pcb]
2021-08-27 Added new Fabrication outputs
    [nogasm-B_Cu.gbr, nogasm-B_Mask.gbr, nogasm-B_Paste.gbr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]
2021-08-27 Annotated Schematic files
    [nogasm.sch]
2022-08-14 Updated to new KicadFormat
    [leds.kicad_sch, leds.sch, nogasm.kicad_pcb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]
2022-08-25 Updated pcb layout and 3d model
    [nogasm.kicad_pcb]
2023-01-13 fixed missing ground and vcc for 2 leds because of esp keepout
    [nogasm.kicad_pcb]
2023-03-01 added 3D files for case
    [Case.step, CaseLower.stl, CaseUpper.stl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]
2024-05-02 updated parts for jlc
    [leds.kicad_sch, nogasm.kicad_pcb, nogasm.kicad_sch]
2024-12-10 updated pindefinitions to match kicad
